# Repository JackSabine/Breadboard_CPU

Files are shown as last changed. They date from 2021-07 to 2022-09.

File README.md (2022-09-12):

# Breadboard CPU

Breadboard CPU LCD writes "Hello, World"!

There's a novelty of creating a computer, however simplified, on breadboards.  You get to see all the LEDs firing, debug easily (?), and show it to anyone!  Who doesn't love flashy lights and lots of wires?

This is a single-instruction Harvard architecture 8-bit CPU.  It uses 16-bit addressing for memories.  There are 8 general-purpose registers, a stack pointer, and a program counter.

## ISA

To create a simple enough CPU that can still function, a custom ISA was created.

A summary is shown below, but the full ISA detail is shown on [Google Drive](https://docs.google.com/spreadsheets/d/1wT5JbnBH3hQDt6mVYworVms3PI7omDdNeonjpWtr__I/edit?usp=sharing) (as long as my NCSU Google Drive is still alive :) ).

### Summary:

* Math operations: add(i), and(i), or(i), not, cmp (subtraction and update status bits)
* Jumps (conditional and unconditional): call, ret, start, jmp, jo, jno, jz, jnz, js, jns, jc, jnc, trap
* Loads/stores: lea, ld, ldr, str, push, pop, stp(i) -- write device to output ports
* Special register manipulation: setsp, cpysp
* Debug: pause

## Programming

All versions of the assembler are retained for different ISA assembler versions.  Programs in `Programming/Programs` are example code using the commented version of the ISA/Assembler. 

## Hardware

Schematics were created using KiCAD, present in `KiCAD`.  It shall correspond to the hardware present on the actual breadboards.

### Hardware/Mixed-Signal Problems

Breadboards have no ground plane, which presents signal integrity problems (e.g. register being reset if ground voltage rises too high).

Shown is the ground line at the corner of the breadboard construction measured by an oscilloscope.  The magnitudes are likely incorrect because the ground lead was unconnected, but the relative magnitudes can explain the observed phenomena.

Ground bounce observed

This can be mitigated by:
1. Installing a ground plane (expensive, inconvenient)
2. Joining the grounds of the transmit and receive ICs (have to fix for each problem register, can get messy)

The second option was taken and is shown below.

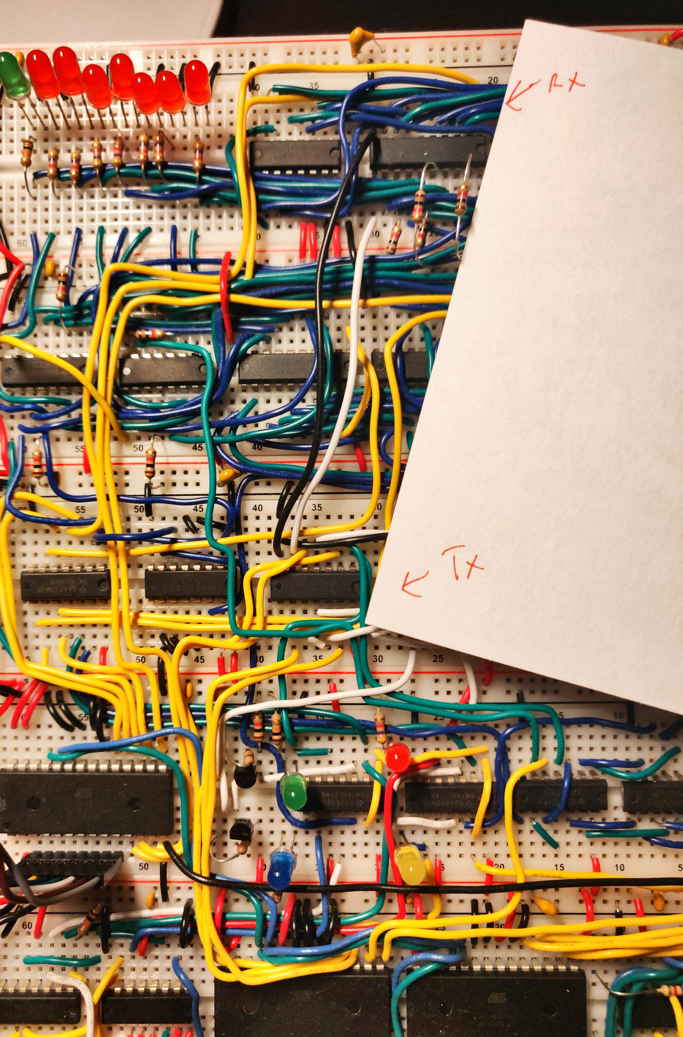
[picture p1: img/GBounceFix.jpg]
Joining ground of transmit and receive ICs


The result of this fix is a register that no longer randomly clears and a reduced ground bounce!

Magnitude of ground bounce reduced as a result of the prior fix

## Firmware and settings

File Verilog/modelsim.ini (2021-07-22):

; Copyright 1991-2017 Mentor Graphics Corporation
;
; All Rights Reserved.
;
; THIS WORK CONTAINS TRADE SECRET AND PROPRIETARY INFORMATION WHICH IS THE PROPERTY OF 
; MENTOR GRAPHICS CORPORATION OR ITS LICENSORS AND IS SUBJECT TO LICENSE TERMS.
;   

[Library]
others = $MODEL_TECH/../modelsim.ini
;
; VITAL concerns:
;
; The library ieee contains (among other packages) the packages of the
; VITAL 2000 standard.  When a design uses VITAL 2000 exclusively, it should use
; the physical library ieee (recommended), or use the physical library
; vital2000, but not both.  The design can use logical library ieee and/or
; vital2000 as long as each of these maps to the same physical library, either
; ieee or vital2000.
;
; A design using the 1995 version of the VITAL packages, whether or not
; it also uses the 2000 version of the VITAL packages, must have logical library
; name ieee mapped to physical library vital1995.  (A design cannot use library
; vital1995 directly because some packages in this library use logical name ieee
; when referring to the other packages in the library.)  The design source
; should use logical name ieee when referring to any packages there except the
; VITAL 2000 packages.  Any VITAL 2000 present in the design must use logical
; name vital2000 (mapped to physical library vital2000) to refer to those
; packages.
; ieee = $MODEL_TECH/../vital1995
;
; For compatiblity with previous releases, logical library name vital2000 maps
; to library vital2000 (a different library than library ieee, containing the
; same packages).
; A design should not reference VITAL from both the ieee library and the
; vital2000 library because the vital packages are effectively different.
; A design that references both the ieee and vital2000 libraries must have
; both logical names ieee and vital2000 mapped to the same library, either of
; these:
;   $MODEL_TECH/../ieee
;   $MODEL_TECH/../vital2000
;

; Altera Primitive libraries
;
; VHDL Section
;
;
; Verilog Section
;

work = C:/Users/jack/OneDrive/Documents/GitHub/Breadboard_CPU/Verilog/sim/temp/workingDir
[vcom]
; VHDL93 variable selects language version as the default. 
; Default is VHDL-2002.
; Value of 0 or 1987 for VHDL-1987.
; Value of 1 or 1993 for VHDL-1993.
; Default or value of 2 or 2002 for VHDL-2002.
; Value of 3 or 2008 for VHDL-2008
VHDL93 = 2002

; Show source line containing error. Default is off.
; Show_source = 1

; Turn off unbound-component warnings. Default is on.
; Show_Warning1 = 0

; Turn off process-without-a-wait-statement warnings. Default is on.
; Show_Warning2 = 0

; Turn off null-range warnings. Default is on.
; Show_Warning3 = 0

; Turn off no-space-in-time-literal warnings. Default is on.
; Show_Warning4 = 0

; Turn off multiple-drivers-on-unresolved-signal warnings. Default is on.
; Show_Warning5 = 0

; Turn off optimization for IEEE std_logic_1164 package. Default is on.
; Optimize_1164 = 0

; Turn on resolving of ambiguous function overloading in favor of the
; "explicit" function declaration (not the one automatically created by
; the compiler for each type declaration). Default is off.
; The .ini file has Explicit enabled so that std_logic_signed/unsigned
; will match the behavior of synthesis tools.
Explicit = 1

; Turn off acceleration of the VITAL packages. Default is to accelerate.
; NoVital = 1

; Turn off VITAL compliance checking. Default is checking on.
; NoVitalCheck = 1

; Ignore VITAL compliance checking errors. Default is to not ignore.
; IgnoreVitalErrors = 1

; Turn off VITAL compliance checking warnings. Default is to show warnings.
; Show_VitalChecksWarnings = 0

; Keep silent about case statement static warnings.
; Default is to give a warning.
; NoCaseStaticError = 1

; Keep silent about warnings caused by aggregates that are not locally static.
; Default is to give a warning.
; NoOthersStaticError = 1

; Treat as errors:
;   case statement static warnings
;   warnings caused by aggregates that are not locally static
; Overrides NoCaseStaticError, NoOthersStaticError settings.
; PedanticErrors = 1

; Turn off inclusion of debugging info within design units.
; Default is to include debugging info.
; NoDebug = 1

; Turn off "Loading..." messages. Default is messages on.
; Quiet = 1

; Turn on some limited synthesis rule compliance checking. Checks only:
;    -- signals used (read) by a process must be in the sensitivity list
; CheckSynthesis = 1

; Activate optimizations on expressions that do not involve signals,
; waits, or function/procedure/task invocations. Default is off.
; ScalarOpts = 1

; Turns on lint-style checking.
; Show_Lint = 1

; Require the user to specify a configuration for all bindings,
; and do not generate a compile time default binding for the
; component. This will result in an elaboration error of
; 'component not bound' if the user fails to do so. Avoids the rare
; issue of a false dependency upon the unused default binding.
; RequireConfigForAllDefaultBinding = 1
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

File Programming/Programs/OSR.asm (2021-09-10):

; Built for ISA v1.0

.ORIG 0x0000

; registers
; r0, r1, r2, r3, r4, r5, r6, r7

; Startup OSR : set PC to program location in memory, configure stack pointer to 0x8200, mark all HSA bytes as 0x00
startup:
    ld      r0,     0x00
    ld      r1,     0x82
    setsp   r0

    ld      r1,     #16
    ld      r2,     0xFF
    ld      r3,     0xFE
    
    call    _lcd_init

; _hsa_lp:
;     str     r0,     r2,     #0
;     add     r3,     #-1
;     add     r1,     #-1
;     jnz     _hsa_lp
_config_env:
    ld      r0,     0x00        ; Default PC 0x0400
    ld      r1,     0x04
    ld      r4,     0x00        ; Default Frame Pointer
    ld      r5,     0x82
    ld      r6,     0x00        ; Default Globals TOS Pointer
    ld      r7,     0x80
    
    start   r0

_lcd_init:
    ; Need RS (4)=0, R/W (5)=0, CE (6)=1, and DB7-DB0=0x00
    ld      r3,     0x00
    ld      r2,     0x01
    str     r3,     r4,     #2      ; PortA = 0x01
    str     r2,     r4,     #3      ; PortB = 0x00

    str     r3,     r4,     #1      ; PortB output mode
    stp     
_lcd_start_fcn_set:
    ld      r1,     0x30            ; 0011 0000 for 0011 **** startup sequence
    str     r1,     r4,     #3

    ld      r0,     #3              ; Clock in 0x30 three times
_lcd_start_fcn_set_lp:
    str     r2,     r4,     #2      ; PortA = 0x00
    ld      r1,     #1              ; wait_lp_1 executes this many times
_lcd_start_fcn_set_lp_wait_lp_1:
    addi    r1,     #-1
    jnz     _lcd_start_fcn_set_lp_wait_lp_1

    str     r3,     r4,     #2      ; PortA = 0x01
    ld      r1,     #1              ; wait_lp_2 executes this many times
_lcd_start_fcn_set_lp_wait_lp_2:
    add     r1,     #-1
    jnz     _lcd_start_fcn_set_lp_wait_lp_2

    add     r0,     #-1
    jnz     _lcd_start_fcn_set_lp

    ld      r1,     0x38            ; 0011 1000 for Function Set N = 1 (multi-line display) and F = 0 (5x8 dot character)
    str     r1,     r4,     #3
    str     r2,     r4,     #2      ; PortA = 0x00
    str     r3,     r4,     #2      ; PortA = 0x01

    ld      r1,     0x08            ; 0000 1000 for Display ON/OFF control (enforced D = 0, C = 0, B = 0 during initialization)
    str     r1,     r4,     #3
    str     r2,     r4,     #2      ; PortA = 0x00
    str     r3,     r4,     #2      ; PortA = 0x01

    ld      r1,     0x01            ; 0000 0001 for Clear Display (sets 20H to all DDRAM locs, 00H to DDRAM addr, return cursor to original position)
    str     r1,     r4,     #3
    str     r2,     r4,     #2      ; PortA = 0x00
    str     r3,     r4,     #2      ; PortA = 0x01

    ld      r1,     0x06            ; 0000 0110 for Entry Mode Set with I/D = 1 for the cursor to move right and SH to 0 to not shift the display
    str     r1,     r4,     #3
    str     r2,     r4,     #2      ; PortA = 0x00
    str     r3,     r4,     #2      ; PortA = 0x01

    ld      r1,     0x0F            ; 0000 1111 for Display ON/OFF control (set Display (on) = 1, Cursor (on) = 1, cursor Blink (on) = 1)
    str     r1,     r4,     #3
    str     r2,     r4,     #2      ; PortA = 0x00
    str     r3,     r4,     #2      ; PortA = 0x01
    ; Display initialized

    ret

; Begin OSR code
sprint_routine:
    ret

; Alloc OSR : need N passed on stack consecutive blocks in heap (using first fit algorithm)
; STACK
;   5+  HSAPL and Mask pair bytes
;   4   HSAP[H]
;   3   HSAP[L]
;   2   i
;   1   TOBins
;   0   COBins
;  -1   OldFramePointer[H]
;  -2   OldFramePointer[L]
;  -3   RetVal[H]
;  -4   RetVal[L]
;  -5   N
alloc:
    ld      r0,     #0              ; Reset r0 to 0
    push    r0                      ; Make space for RetVal
    push    r0                      ; ""
    push    r4                      ; Save FramePointer
    push    r5                      ; ""
    cpysp   r4                      ; Get new FramePointer
    push    r0                      ; Make space for COBins
    push    r0                      ; TOBins
    ld      r2,     #16             ; For loop iteration i = 16
    push    r2                      ; Set i in stack
    ld      r0,     xFF             ; HSAP
    push    r0
    ld      r0,     xFE
    push    r0
_BLK_FINDER_LP:
    ld      r2,     #1              ; Configure mask
    ld      r3,     #8              ; Internal for loop iteration j = 8
_INNER_LP:
    ldr     r0,     r4,     #3      ; Get low byte of HSAP
    ldr     r1,     r4,     #4      ; Get high byte of HSAP
    ldr     r1,     r0,     #0      ; Get value at HSAP
    and     r1,     r2              ; Test r1 with Mask in r2
    jz      _OPEN_FOUND
    ; Blocked section... reset contiguous bin counter and pop off all pairs pushed
    ldr     r0,     r4,     #0      ; Load COBins
    jz      _OPEN_NOT_FOUND_FIN
_OPEN_NOT_FOUND_PAIR_POP_LP:
    ; If COBins is not zero, then we have to pop the HSAP low byte and mask pairs off the stack
    pop     r1
    pop     r1
    add     r0,     #-1
    jnz     _OPEN_NOT_FOUND_PAIR_POP_LP
_OPEN_NOT_FOUND_RESTORE_COBINS:
    str     r0,     r4,     #0      ; Set COBins back to 0
_OPEN_NOT_FOUND_FIN:
    add     r2,     r2              ; Mask = Mask + Mask (or effectively Mask = Mask << 1)
    j     _INC_INNER
_OPEN_FOUND:
    ; Coming into this block with HSAP low byte in r0 and mask in r2
    ; Next, push the low byte HSAP to the stack along with its mask
    push    r0
    push    r2

    ldr     r0,     r4,     #1      ; Load TOBins
    add     r0,     #1              ; Increment TOBins
    str     r0,     r4,     #1      ; Store TOBins back on stack
    ldr     r0,     r4,     #0      ; Load COBins
    add     r0,     #1              ; Increment COBins
    ldr     r1,     r4,     #-5     ; Load N
    cmp     r0,     r1              ; Is N == COBins ?
    jz      _PREP_RET_ADDR
    str     r0,     r4,     #0      ; Store COBins for next iteration
    ; Fall into _INC_INNER
_INC_INNER:
    ldr     r0,     r4,     #3      ; Decrement the low byte of the HSAP
    add     r0,     #-1             ;   No need to check for underflow conditions ->  HSA is 16 bytes long and at the top of its local 8-bit address range
    str     r0,     r4,     #3

    add     r3,     #-1             ; Decrement j for next loop
    jnz      _INNER_LP              ; Test if j > 0 else leave this INNER loop and fall into the outer loop inc _BLK_FINDER_INC
_BLK_FINDER_INC:
    ldr     r0,     r4,     #2      ; Load i (outer loop iterator)
    add     r0,     #-1             ; Decrement i
    jz      _CLEAN_UP_PAIRS             ; i == 0, no more status registers to check
    str     r0,     r4,     #2      ; Continue looping, so store i
    jnz     _BLK_FINDER_LP
_CLEAN_UP_PAIRS:
    ; How many pairs do we have... Given by COBins.
    ldr     r0,     r4,     #0
    jz      _END_ALLOC
_CLEAN_UP_PAIRS_LP:
    pop     r1
    pop     r1
    add     r0,     #-1
    jnz     _CLEAN_UP_PAIRS_LP
    jz      _END_ALLOC
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

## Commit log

2020-07-01 Added hierarchical sheets for different subdivisions. Finished Power Regulator CKT.
    [ALU.sch, Breadboard_CPU.kicad_pcb, Breadboard_CPU.sch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]
2020-07-05 Added clock and program counter modules. Refined some schematics.
    [Breadboard_CPU.sch, Clock.sch, PowerControl.sch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]
2020-07-06 Fixed second Program Counter.
    [Breadboard_CPU.sch, ProgramCounter.sch]
2020-07-26 Continued work. Pushing for remote work.
    [ALU.sch, Breadboard_CPU.sch, Clock.sch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]
2020-07-30 Remote work
    [ALU.sch, Breadboard_CPU.sch, Clock.sch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]
2020-08-02 For desktop work
    [ALU.sch, Breadboard_CPU.sch, Clock.sch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]
2020-08-03 Migrated old device part numbers to SN74 LS or HCT series
    [ALU.sch, Breadboard_CPU.sch, Clock.sch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]
2020-08-08 Added ASSERT_ETI SR latch (NOR) - see timing diagram for int sheet
    [ALU.sch, ControlUnit.sch, Memory.sch]
2020-08-10 Finished int handler (CPU side) and started flags module
    [Breadboard_CPU.sch, ConditionFlags.sch, ControlUnit.sch]
2020-08-13 Pre non-interrupt split
    [ALU.sch, Breadboard_CPU.sch, Clock.sch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]
2020-12-17 Replaced all broken schematics with the up-to-date versions. Some symbols missing. This version will be the one created IRL except for the carry flag.
    [ALU.sch, Breadboard_CPU.sch, Clock.sch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]
2020-12-17 Fixed CFL timing violation bug. TOFIX: move away from rescue .lib symbols and fix the 2x 4:1 mux symbol.
    [Breadboard_CPU.sch]
2021-01-25 Rearranged some generic logic gates in ALU to match physical net connections on the breadboard.
    [ALU.sch, Breadboard_CPU.sch, ControlUnit.sch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]
2021-02-01 Created STM32 and python projects for EEPROM programming
2021-02-24 Abandoned EEPROM programmer project. Purchasd EEPROM programmer.
    [ControlUnit.sch]
2021-03-15 Libraries re-imported. Using rescue symbols still. Adjusted multi-byte registers to use low-byte first.. applied this convention to all multi-byte registers for consistency.
    [Breadboard_CPU.sch, ControlUnit.sch, Memory.sch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]
2021-03-16 Added REGS_ASSERT_RS0. Added user referenceable CFL to solve issue of performing arithmetic on stack frame and global pointers. TRAP routines will be created to perform ADD operations (leveraging JC/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
    [ALU.sch, Breadboard_CPU.sch, ControlUnit.sch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]
2021-05-02 Moved gates in memory.sch to reflect real wire connections
    [Memory.sch]
2021-05-03 Pre-removal of H/L byte deciding hardware
    [Breadboard_CPU.sch, ControlUnit.sch, Memory.sch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]
2021-05-07 Testing memory module
    [ALU.sch, Breadboard_CPU.sch, Clock.sch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]
2021-06-06 Simulating negpulse
    [Breadboard_CPU.sch, Memory.sch]
2021-06-11 Restructured files. Added EEPROM_Programming files.
    [ALU.sch, Breadboard_CPU.kicad_pcb, Breadboard_CPU.sch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]
2021-06-13 Edited SP async->sync converters to use BJT, C, 2R. Use DiLog for RS0|RS[0].
    [Registers.sch]
2021-06-18 Pulled ALU lines high by default. TODO: update SP pulse circuit to reflect new TI chip design.
    [ALU.sch]
2021-06-29 Begin control signal to pin remapping
2021-07-06 Continued developing assembler
    [ALU.sch, Breadboard_CPU.sch, Clock.sch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]
2021-07-09 Update aliases to v1.2; replace VCC with +5V; begin update control signal names to match short aliases on KiCAD. Missing buf reg on IR; missing decouple caps in KiCAD; missing correct pin connections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
    [ALU.sch, Breadboard_CPU.kicad_pcb, Breadboard_CPU.sch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]
2021-07-10 Updated symbols in memory module; updated control line names to their shorter alias; retrieved unencrypted version of KiCAD schematics.
    [ALU.sch, Breadboard_CPU.kicad_pcb, Breadboard_CPU.sch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]
2021-07-11 Moved SP out of register module into SP module; changed RS0 assert signal alias from RS0 to RSH; moved uCode and program code to different subdirs of Programming/ .
    [Breadboard_CPU.sch, Clock.sch, ControlUnit.sch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]
2021-07-16 Corrected asm.py to give correct PC offsets; encountering glitch issue with registers - may consider delaying the uInst counter's clock input.
    [Memory.sch]
2021-07-18 First working versiongit add . Added CSU control signal for updating C and O flags during add operations only. Added circuitry to disable the reg decoder unless ~RI or ~RO are asserted. Potential fut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
    [ALU.sch, Breadboard_CPU.sch, ControlUnit.sch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]
2021-07-22 Began making HelloWorld.asm. Verified clock switching module in Verilog/
2021-07-28 Update ucode for correct push/pop directions; mod asm.py to allow for multiple .ORIG in one file; debugging OSR.asm; potentially FIXED asm_helper.py ambiguous instruction not using imm versions of am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
    [OSR.asm]
2021-09-19 Split Assemble into component functions. Create include search and macro dict.
2021-12-13 restructured file hierarchy for assembler across ISA versions; add printout debugging for assembler interpretation of assembly src
2021-12-13 Add tab after labelname in printout txt
2021-12-14 Add table header to symb. memory print
2021-12-15 Need to replace macros in source file. Adapted ashelp to work with new assembler top level.
2021-12-19 Reorganized files from Utils/ to Assembler/
2021-12-19 Need to fix binary->integer conversion of 11 bit value not sign extending msb
    [OSR_1_1.asm]
2021-12-31 Switch pause and add + successful run of assembler
2022-01-02 String printer works!
2022-01-03 Finish OSR for multiline string prints
    [Clock.sch]
2022-06-22 Upgrade to KiCAD 6 and add Clock synchronizer
    Clock module used to contain a mux, but there would be glitches due to
    synchronization issues when changing between inputs. Opted to reduce
    number of input clocks 4 -> 2 and add a synchronizer between astable
    clock and button.
    [ALU.kicad_sch, Breadboard_CPU.kicad_sch, Clock.kicad_sch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]

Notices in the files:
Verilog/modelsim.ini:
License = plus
